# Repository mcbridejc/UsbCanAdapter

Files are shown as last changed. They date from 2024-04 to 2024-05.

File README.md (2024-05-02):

# USB CAN Adapter

An STM32F0 USB CAN interface. I couldn't find a decent option in stock, so built this. It works,
but is not well documented and should be considered a project not a product ;).

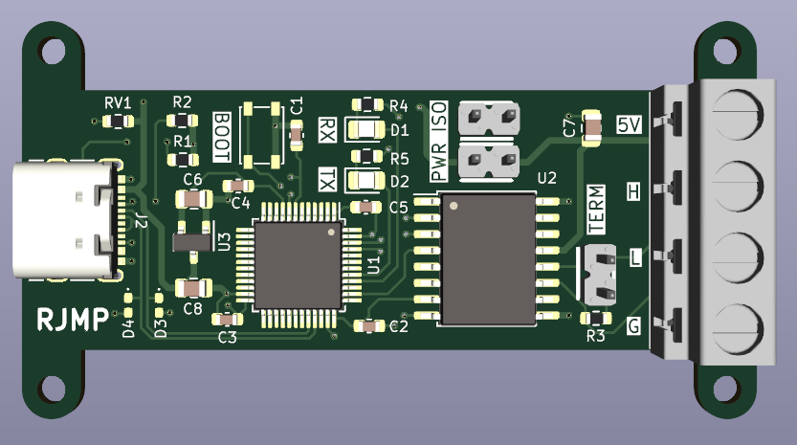
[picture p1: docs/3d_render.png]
3D rendering of USB CAN board USB CAN Render


## Firmware

This board can use the "cantact" firmware from https://github.com/candle-usb/candleLight_fw. In the
release archive, the file is "cantact_fw.bin". It is also included in the repo here for reference.

It can be programmed via the built-in DFU bootloader. To get into boot loader, pull boot0 high while
powering on, using the BOOT0 button (See rev1 errata; some bodge wires are required for this).

On linux, you can use `dfu-util`, like so:

```
dfu-util -D cantact_fw.bin -d 0483:df11 -a 0 -s 0x08000000
```

ST has a DFU programming tool for windows (and there are others)

## Jumpers

There are three shortable jumpers:

- "TERM" connects a 120 ohm termination resistor between CAN_H and CAN_L.
- "POWER_ISO" (two jumpers) connect the USB 5V and ground to the isolated CAN bus side of the
  transceiver. If these are left unconnected, the CAN bus is electrically isolated from the MCU/USB
  side of the board, but 5V must be provided from elsewhere.

## Reminders for using on linux

`sudo ip link set can0 type can bitrate 1000000`
`sudo ip link set up can0 txqueuelen 1024`

For a GUI, SavvyCAN works. Create the connection as a "QT SerialBus" device, with devicetype "socketcan". It seems the link must be manually brought up and bitrate set on the command line first; savvy can isn't going it (maybe because of permissions?).

## Rev 1 Errata

- The BOOT0 button is backwards. It should be grounded by default and pulled high by the button.
- The jumper holes are too small for most 0.1" headers and need to be enlarged.

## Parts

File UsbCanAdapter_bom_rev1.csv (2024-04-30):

Component | Description | Part | References | Value | Footprint | Quantity Per PCB | Datasheet | Mfg Part Number | DK Part Number
1 | Unpolarized capacitor, small symbol | C_Small | C1 C2 C3 C4 C5 | 0.1u | C_0603_1608Metric | 5 | ~
2 | Unpolarized capacitor, small symbol | C_Small | C6 C7 C8 | 4.7u | C_0805_2012Metric | 3 | ~
3 | Light emitting diode | LED | D1 D2 | LED | LED_0805_2012Metric | 2 | ~
4 | Zener diode, small symbol, filled shape | D_Zener_Small_Filled | D3 D4 | TVS | D_0402_1005Metric_Pad0.77x0.64mm_HandSolder | 2 | ~
5 | Generic connector, single row, 01x05, script generated (kicad-library-utils/schlib/autogen/connector/) | Conn_01x05 | J3 | SWD Pads | SWD_PADS | 1 | ~
6 | Generic screw terminal, single row, 01x04, script generated (kicad-library-utils/schlib/autogen/connector/) | Screw_Terminal_01x04 | J1 | Screw_Terminal_01x04 | 1776119-4 | 1 | ~ | 1776119-4
7 | USB 2.0-only Type-C Receptacle connector | USB_C_Receptacle_USB2.0 | J2 | USB_C_Receptacle_USB2.0 | USB_C_Receptacle_GCT_USB4105-xx-A_16P_TopMnt_Horizontal | 1 | https://www.usb.org/sites/default/files/documents/usb_type-c.zip
8 | Jumper, 2-pole, open | Jumper_2_Open | JP1 JP2 JP3 | Jumper | short_jumper | 3 | ~
9 | Resistor, small US symbol | R_Small_US | R3 | 120 | R_0603_1608Metric | 1 | ~
10 | Resistor, small US symbol | R_Small_US | R4 R5 | 240 | R_0603_1608Metric | 2 | ~
11 | Resistor, small US symbol | R_Small_US | R1 R2 | 5.1k | R_0603_1608Metric | 2 | ~
12 | Voltage dependent resistor | Varistor | RV1 | TVS MLA Varistor | R_0603_1608Metric | 1 | ~
13 | Push button switch, generic, two pins | SW_Push | SW1 | SW_Push | SW_SPST_PTS810 | 1 | ~ | PTS810 SJM 250 SMTR LFS | CKN10502CT-ND
14 | 250mA Low Quiscent Current LDO, 3.3V output, SOT-23 | MCP1700x-330xxTT | U3 | MCP1700x-330xxTT | SOT-23 | 1 | http://ww1.microchip.com/downloads/en/DeviceDoc/20001826D.pdf
15 | STMicroelectronics Arm Cortex-M0 MCU, 32KB flash, 6KB RAM, 48 MHz, 2.0-3.6V, 38 GPIO, LQFP48 | STM32F042C6Tx | U1 | STM32F042C6Tx | LQFP-48_7x7mm_P0.5mm | 1 | https://www.st.com/resource/en/datasheet/stm32f042c6.pdf
16 |  | ADB3054 | U2 | ~ | SOIC-16W_7.5x10.3mm_P1.27mm | 1 |  | ADM3054WBRWZ-RL7
Component Groups: | 16
Component Count: | 28
Fitted Components: | 28
Number of PCBs: | 1
Total components: | 28
Schematic Version:
Schematic Date:
PCB Variant: | default
BoM Date: | Sat 18 Mar 2023 11:25:42 AM PDT
Schematic Source: | UsbCanAdapter.kicad_sch
KiCad Version: | Eeschema 7.0.0-da2b9df05c~171~ubuntu22.04.1

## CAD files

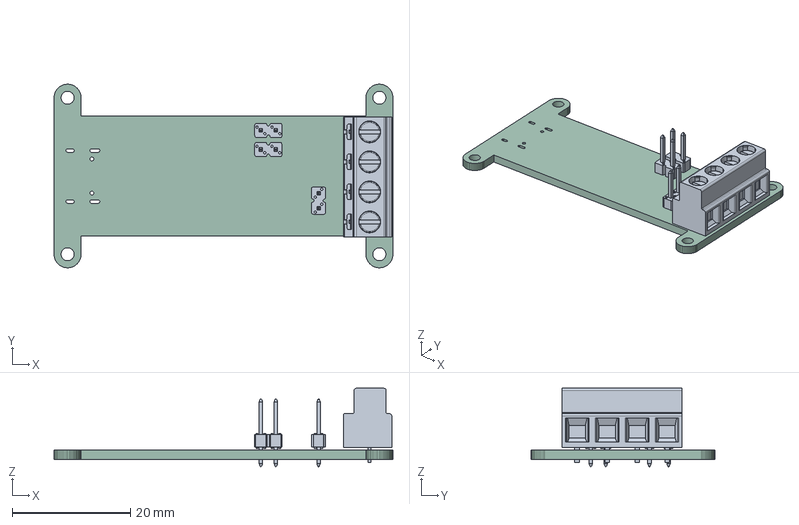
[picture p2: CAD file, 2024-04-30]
UsbCanAdapter.step
57.4 x 31.1 x 13.3 mm
PCB

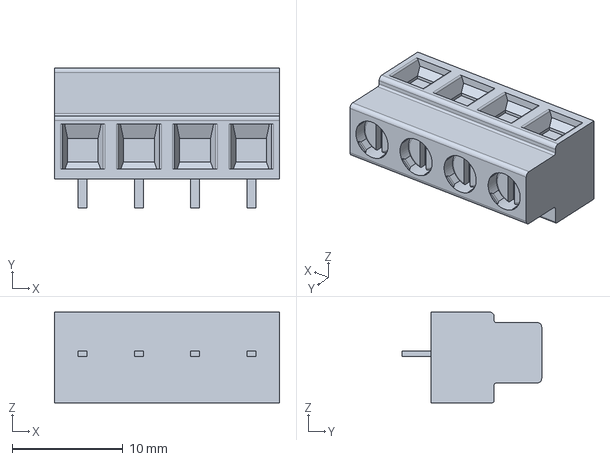
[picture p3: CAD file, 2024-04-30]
c-1776119-4-b-3d.stp
20.3 x 12.6 x 8.20 mm

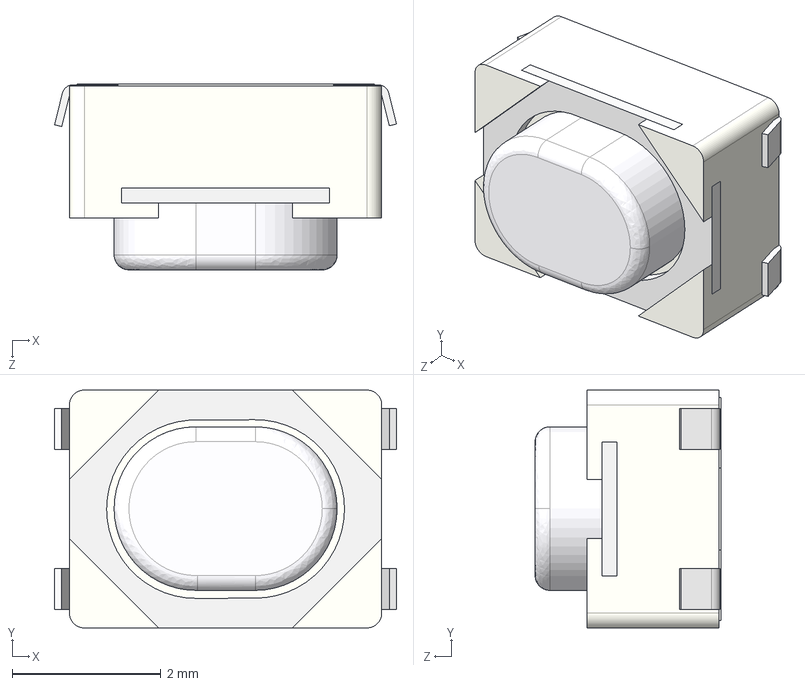
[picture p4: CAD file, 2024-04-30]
PTS810.STEP
4.60 x 3.20 x 2.50 mm
Strip
Button
Sheet Metal Part6 x 2
Pin

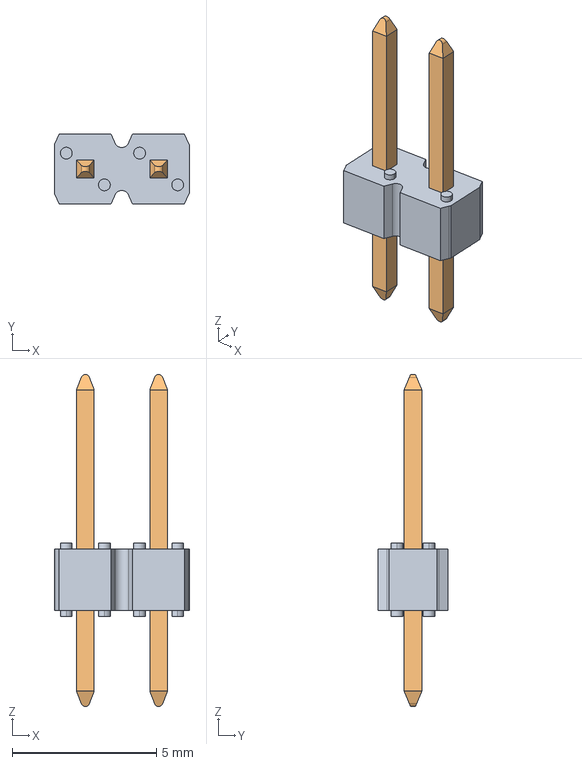
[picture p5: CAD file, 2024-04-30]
77311-y18-02_asm.stp
4.68 x 2.41 x 11.5 mm
77310_Y16 x 2

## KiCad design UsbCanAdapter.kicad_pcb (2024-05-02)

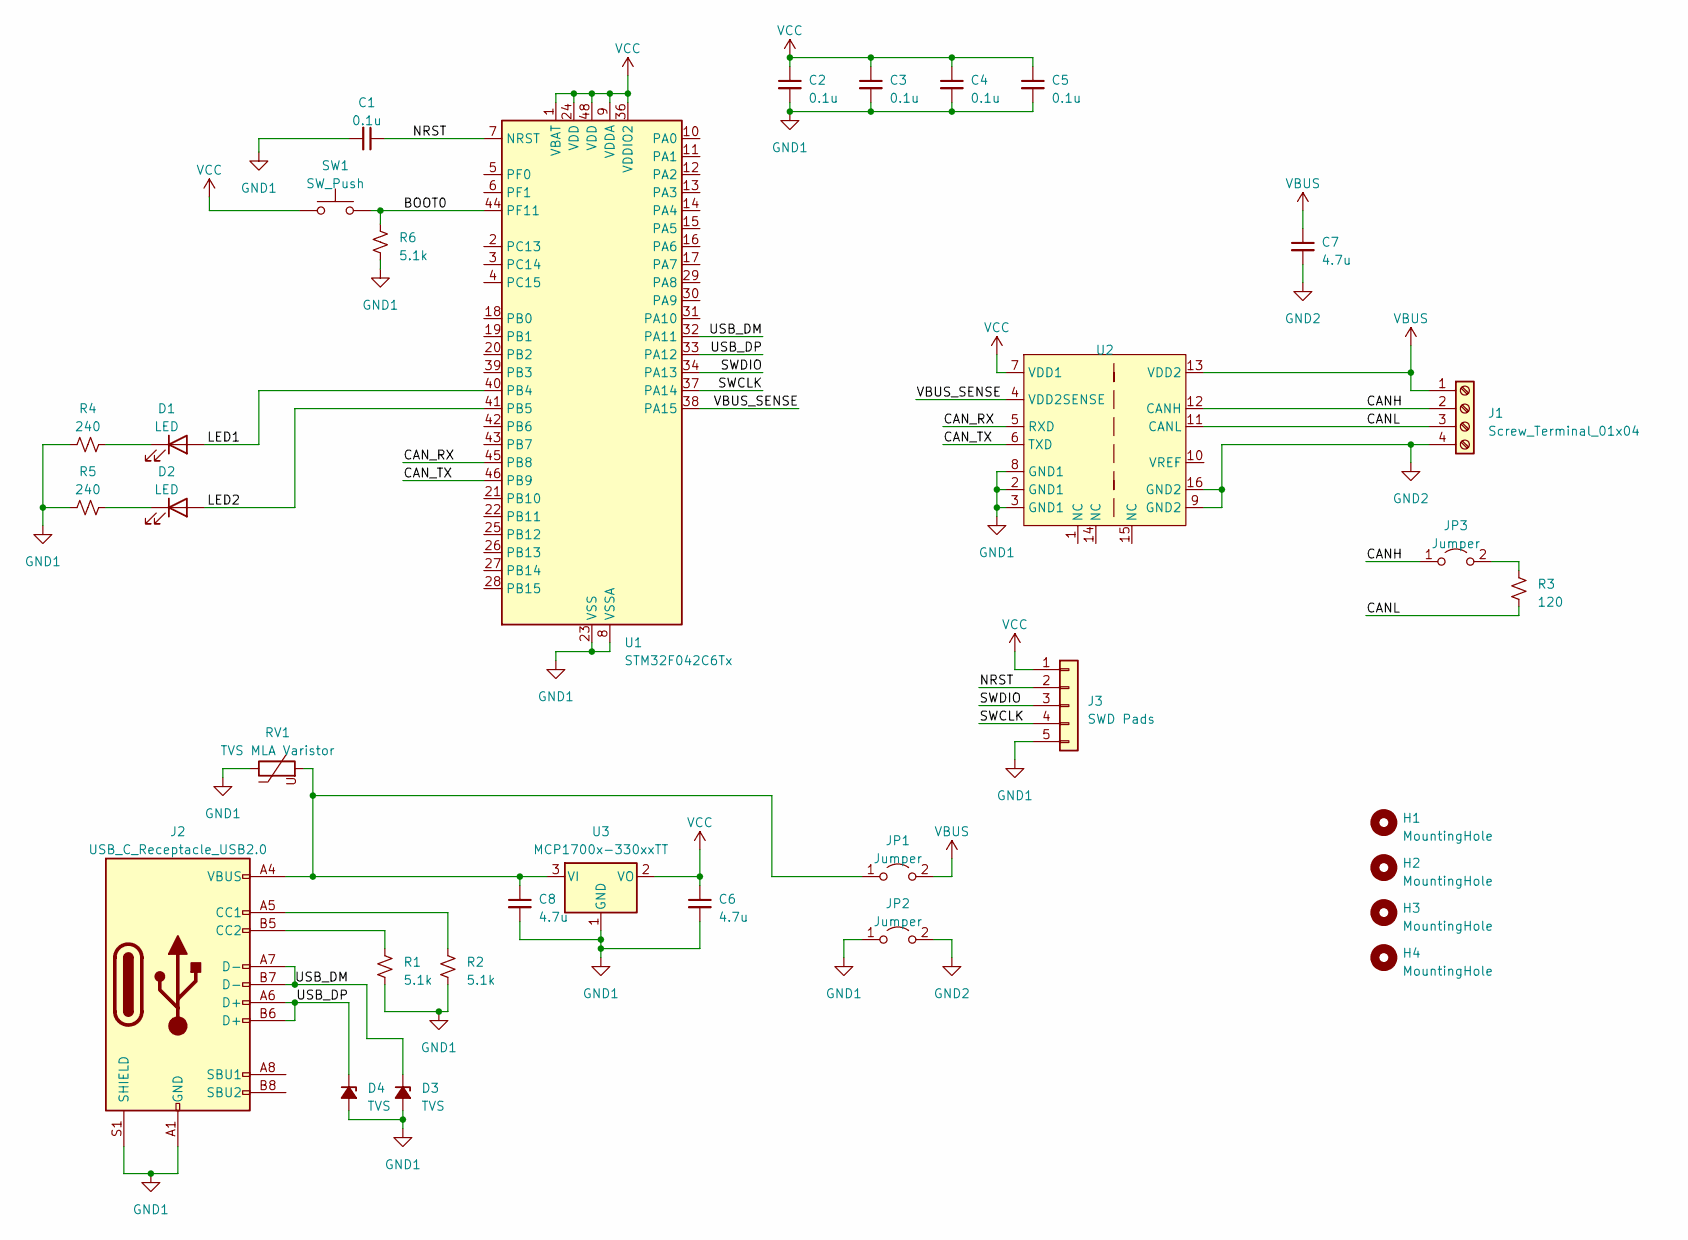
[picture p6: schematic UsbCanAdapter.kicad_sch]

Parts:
C1, C2, C3, C4, C5: 0.1u; C_0603_1608Metric
C6, C7, C8: 4.7u; C_0805_2012Metric
D1, D2: LED; LED_0805_2012Metric
D3, D4: TVS; D_0402_1005Metric_Pad0.77x0.64mm_HandSolder
H1, H2, H3, H4: MountingHole; MountingHole_2.2mm_M2
J1: Screw_Terminal_01x04; 1776119-4; Mfg Part Number 1776119-4
J2: USB_C_Receptacle_USB2.0; USB_C_Receptacle_GCT_USB4105-xx-A_16P_TopMnt_Horizontal
J3: SWD Pads; SWD_PADS
JP1, JP2, JP3: Jumper; short_jumper
R1, R2, R6: 5.1k; R_0603_1608Metric
R3: 120; R_0603_1608Metric
R4, R5: 240; R_0603_1608Metric
RV1: TVS MLA Varistor; R_0603_1608Metric
SW1: SW_Push; SW_SPST_PTS810; Mfg Part Number PTS810 SJM 250 SMTR LFS
U1: STM32F042C6Tx; LQFP-48_7x7mm_P0.5mm
U2: SOIC-16W_7.5x10.3mm_P1.27mm; Mfg Part Number ADM3054WBRWZ-RL7
U3: MCP1700x-330xxTT; SOT-23

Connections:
/BOOT0: R6.1, SW1.2, U1.44 (PF11)
/CANH: J1.2, JP3.1 (A), U2.12 (CANH)
/CANL: J1.3, R3.1, U2.11 (CANL)
/CAN_RX: U1.45 (PB8), U2.5 (RXD)
/CAN_TX: U1.46 (PB9), U2.6 (TXD)
/LED1: D1.2 (A), U1.40 (PB4)
/LED2: D2.2 (A), U1.41 (PB5)
/NRST: C1.1, J3.2, U1.7 (NRST)
/SWCLK: J3.4, U1.37 (PA14)
/SWDIO: J3.3, U1.34 (PA13)
/USB_DM: D3.1 (K), J2.A7 (D-), J2.B7 (D-), U1.32 (PA11)
/USB_DP: D4.1 (K), J2.A6 (D+), J2.B6 (D+), U1.33 (PA12)
/VBUS_SENSE: U1.38 (PA15), U2.4 (VDD2SENSE)
GND1: C1.2, C2.2, C3.2, C4.2, C5.2, C6.2, C8.2, D3.2 (A), D4.2 (A), J2.A1 (GND), J2.A12 (GND), J2.B1 (GND), J2.B12 (GND), J2.S1 (SHIELD), J3.5, JP2.1 (A), R1.2, R2.2, R4.1, R5.1, R6.2, RV1.1, U1.8 (VSSA), U1.23 (VSS), U1.35 (VSS), U1.47 (VSS), U2.2 (GND1), U2.3 (GND1), U2.8 (GND1), U3.1 (GND)
GND2: C7.2, J1.4, JP2.2 (B), U2.9 (GND2), U2.16 (GND2)
unnamed: D1.1 (K), R4.2
unnamed: D2.1 (K), R5.2
unnamed: J2.A5 (CC1), R2.1
unnamed: J2.B5 (CC2), R1.1
unnamed: C8.1, J2.A4 (VBUS), J2.A9 (VBUS), J2.B4 (VBUS), J2.B9 (VBUS), JP1.1 (A), RV1.2, U3.3 (VI)
unnamed: JP3.2 (B), R3.2
VBUS: C7.1, J1.1, JP1.2 (B), U2.13 (VDD2)
VCC: C2.1, C3.1, C4.1, C5.1, C6.1, J3.1, SW1.1, U1.1 (VBAT), U1.9 (VDDA), U1.24 (VDD), U1.36 (VDDIO2), U1.48 (VDD), U2.7 (VDD1), U3.2 (VO)

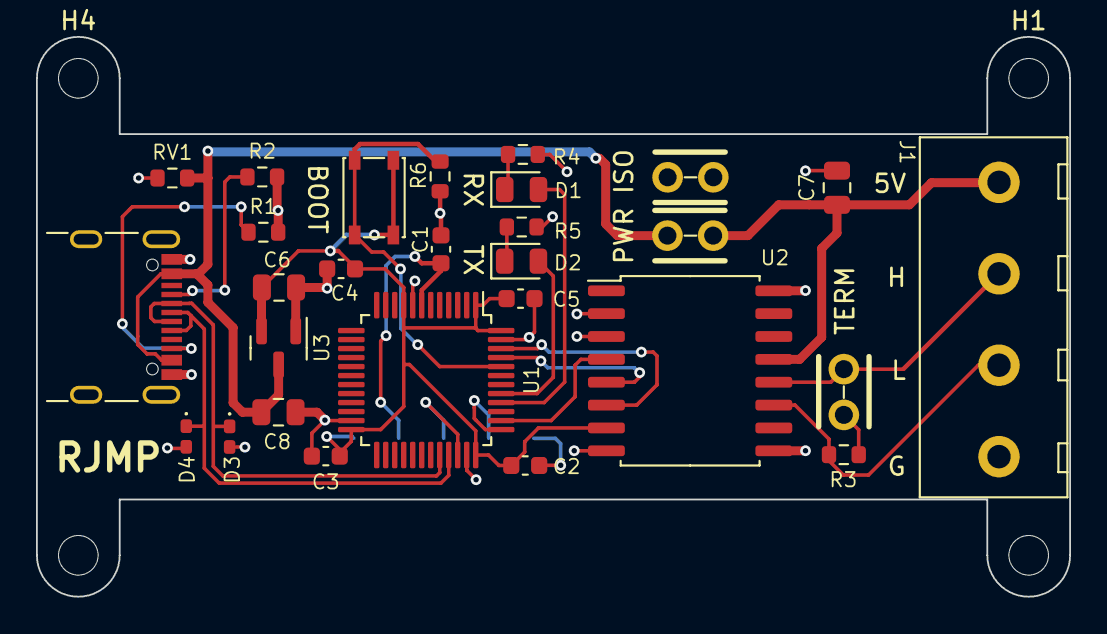
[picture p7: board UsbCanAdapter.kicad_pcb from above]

Board: 2 copper layers, 57.4 x 31.1 mm, 33 parts (1 on the bottom side), 23 nets.

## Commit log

2024-04-30 initial commit of rev1 design
    [77311-y18-02_asm.stp, PTS810.STEP, UsbCanAdapter.kicad_pcb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]
2024-04-30 rev1 gerbers
    [UsbCanAdapter-B_Cu.gbr, UsbCanAdapter-B_Mask.gbr, UsbCanAdapter-B_Paste.gbr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]
2024-04-30 Fix rev1 issues
    - reverse BOOT0 pin polarity
    - enlarge short jumper holes to 1mm
    [UsbCanAdapter.kicad_pcb, UsbCanAdapter.kicad_sch]
2024-05-02 Update PCB design for rev2 changes
    [UsbCanAdapter.kicad_pcb]
